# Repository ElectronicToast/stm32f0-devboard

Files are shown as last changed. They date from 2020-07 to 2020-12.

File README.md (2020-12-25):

# stm32f0-devboard
 

A minimal development board featuring an STM32F030C8T6

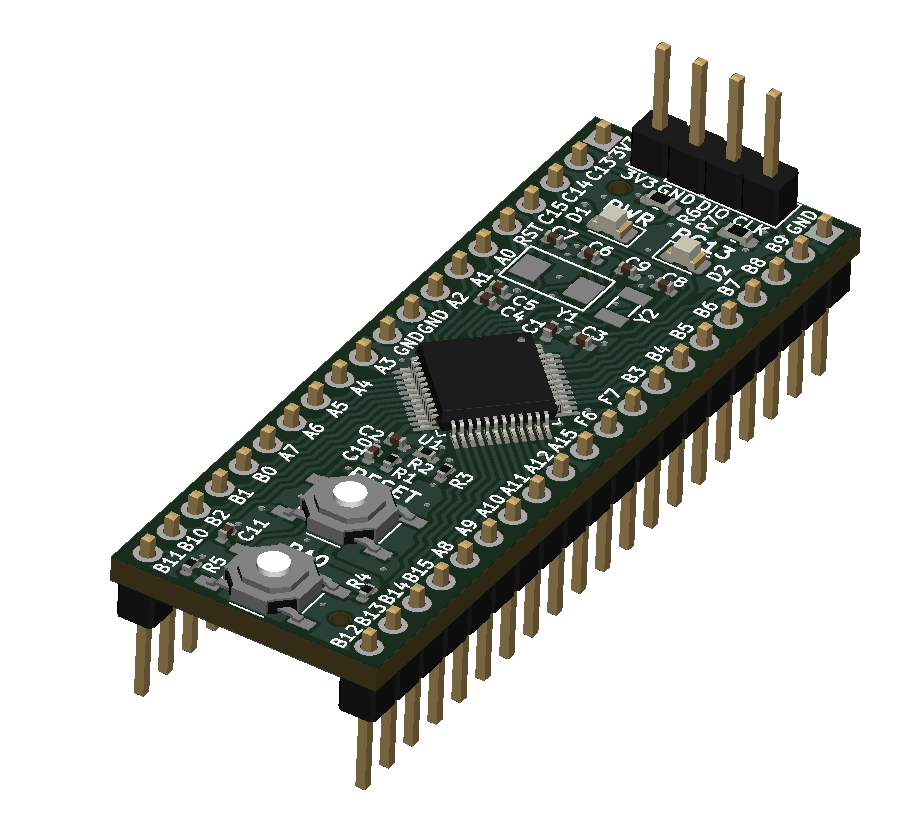
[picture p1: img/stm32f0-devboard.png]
iso


## Description
This is a minimal development board for STM32F0xxC MCUs designed for ease of turnkey assembly by JLCPCB Co. Ltd. The board includes HSE and LSE oscillators, reset and user button, power and user LED, BOOT0 boot mode select solder jumper, and a SWD programming header. All components, sans connectors, can be assembled by JLCPCB, and tooling holes for the SMT assembly process are provided.

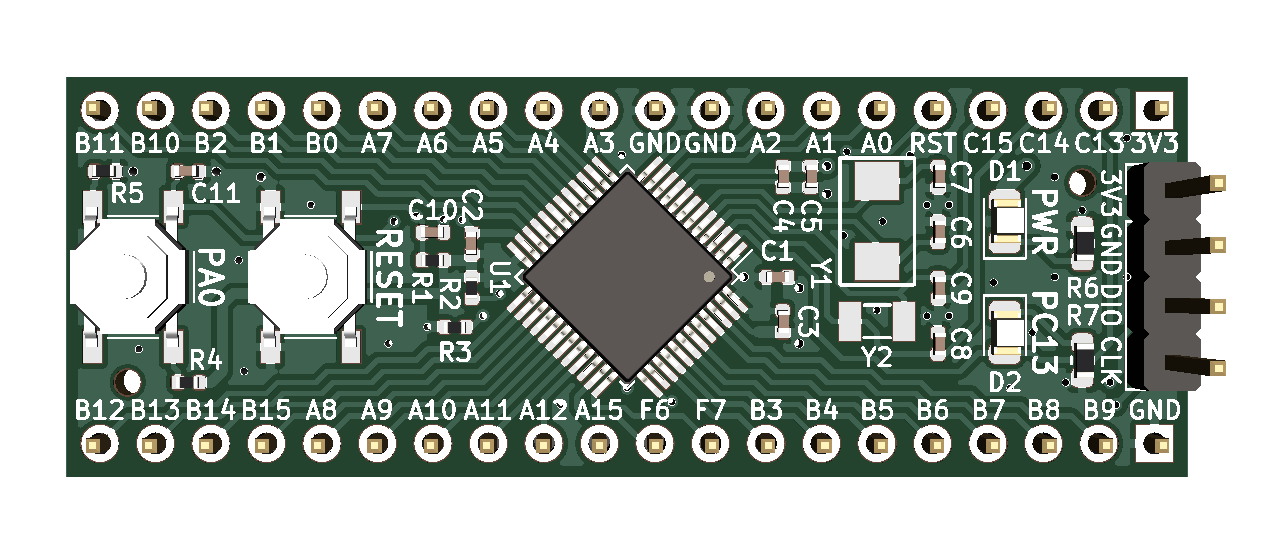
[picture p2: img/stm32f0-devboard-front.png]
front

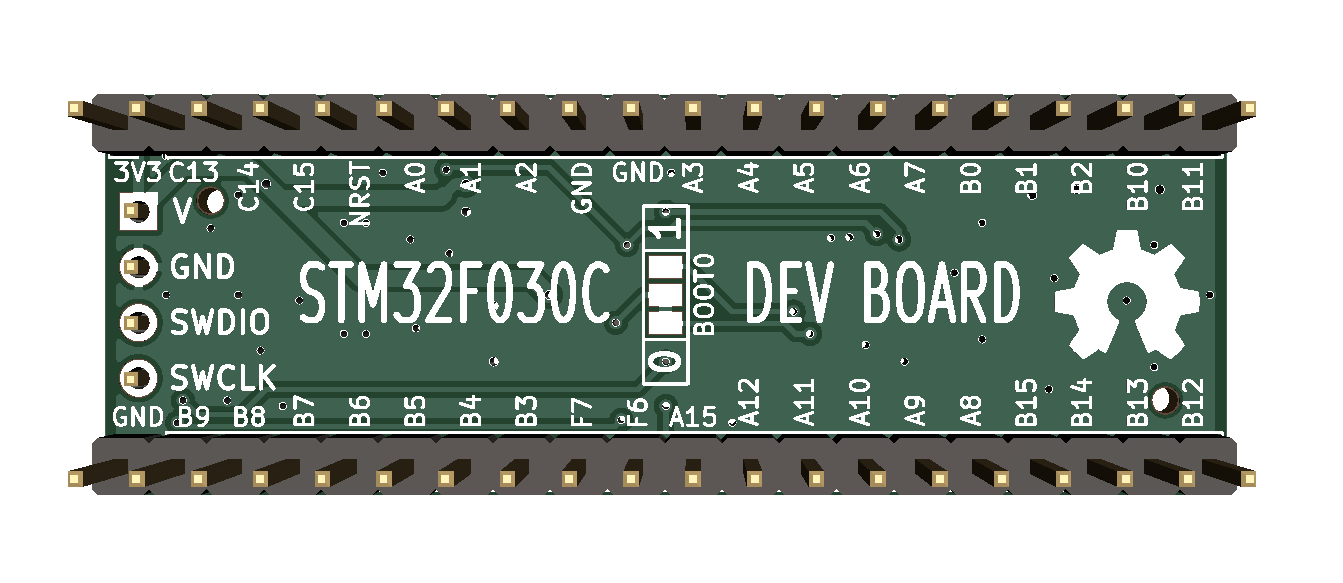
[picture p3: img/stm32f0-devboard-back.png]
back


## Licensing
This project is released under the terms of the MIT License.

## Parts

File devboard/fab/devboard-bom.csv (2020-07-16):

Comment | Designator | Footprint | LCSC Part#
4.7uF | C1 | 0402_C | C23733
100nF | C2,C3,C10,C11 | 0402_C | C1525
10nF | C4 | 0402_C | C15195
1uF | C5 | 0402_C | C52923
33pF | C6,C7 | 0402_C | C1562
18pF | C8,C9 | 0402_C | C1549
FC-2012HRK-620D Red 0603 | D1 | 0805_LED | C84256
C2293 Blue LED | D2 | 0805_LED | C2293
10K | R2,R3,R1,R4 | 0402_R | C25744
100 | R5 | 0402_R | C25076
510 | R6 | 0603_R | C23193
330 | R7 | 0603_R | C23138
TS-1187A-C-C-B | SW1,SW2 | SW-4_5.1x5.1x1.7 | C318889
STM32F030C8T6 | U1 | LQFP48 | C23922
X50328MSB2GI 8MHz | Y1 | SMD-5032_2P | C115962
Q13FC1350000400 32.768kHz | Y2 | SMD-3215_2P | C32346

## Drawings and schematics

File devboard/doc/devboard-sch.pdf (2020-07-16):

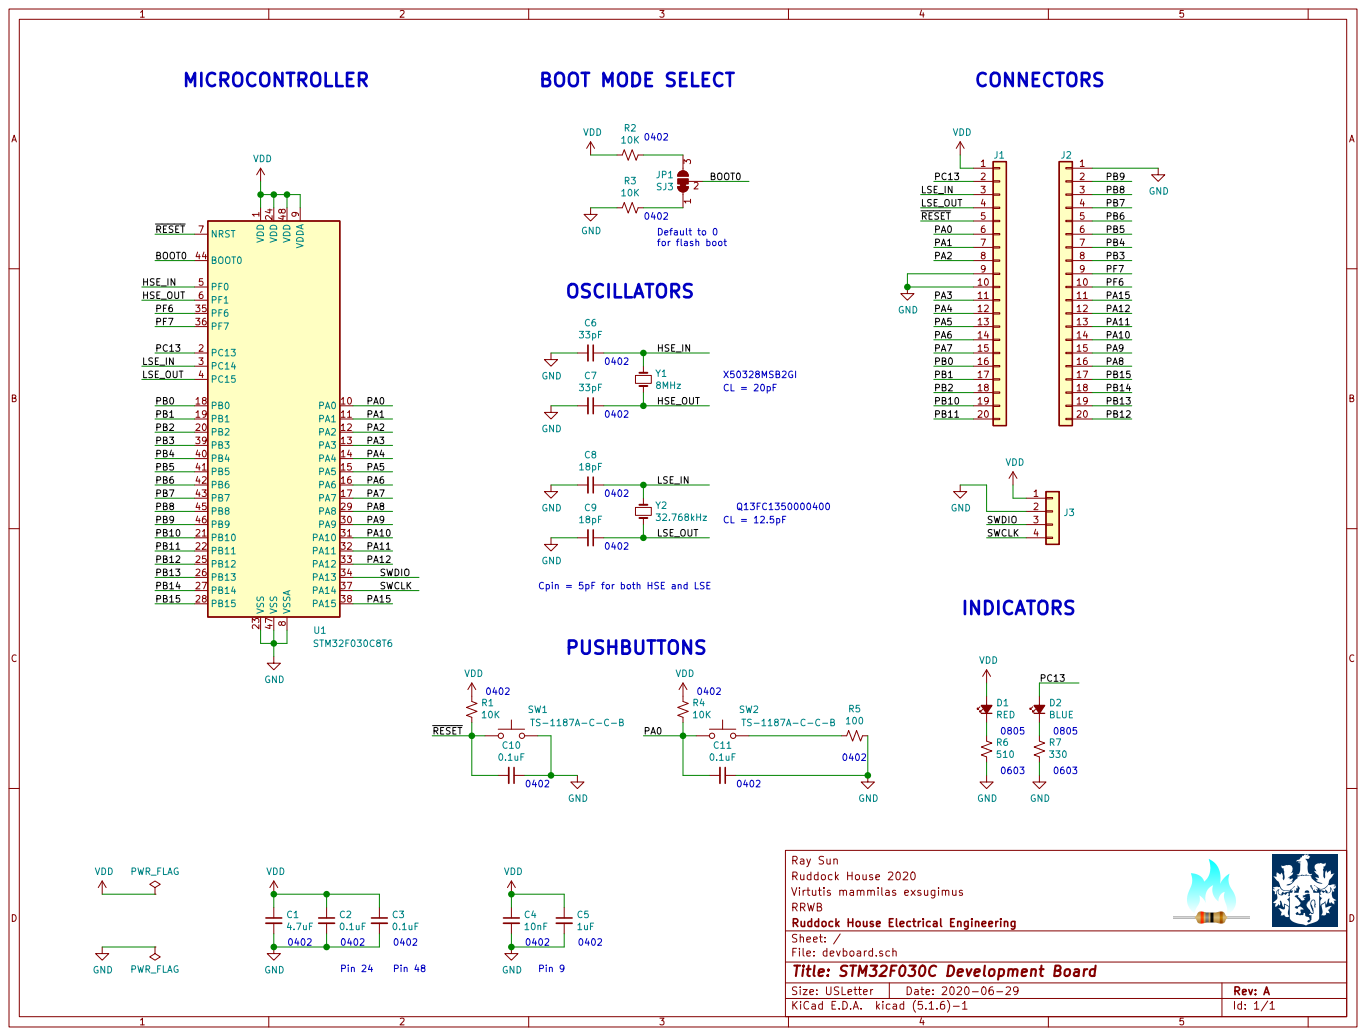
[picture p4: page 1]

1 PA0 10 PA1 11 PA2 12 PA3 13 PA4 14 PA5 15 PA6 16 PA7 17 PB0 18 PB1 19 PC13 2 PB2 20 PB10 21 PB11 22 VSS 23 VDD 24 PB12 25 PB13 26 PB14 27 PB15 28 PA8 29 PC14 3 PA9 30 PA10 31 PA11 32 PA12 33 PA13 34 PF6 35 PF7 36 PA14 37 PA15 38 PB3 39 PC15 4 PB4 40 PB5 41 PB6 42 PB7 43 BOOT0 44 PB8 45 PB9 46 VSS 47 VDD 48 PF0 5 PF1 6 NRST 7 VSSA

Cpin = 5pF for both HSE and LSE

Virtutis mammilas exsugimus Ruddock House 2020 Ray Sun

File: devboard.sch Sheet: / Ruddock House Electrical Engineering RRWB

Id: 1/1 Title: STM32F030C Development Board

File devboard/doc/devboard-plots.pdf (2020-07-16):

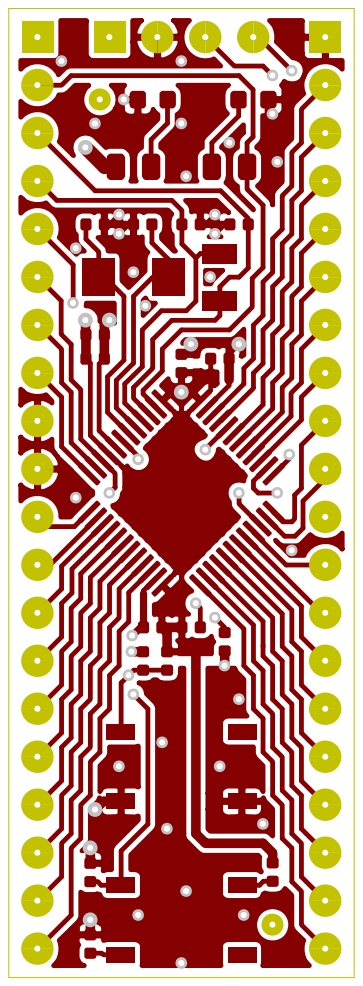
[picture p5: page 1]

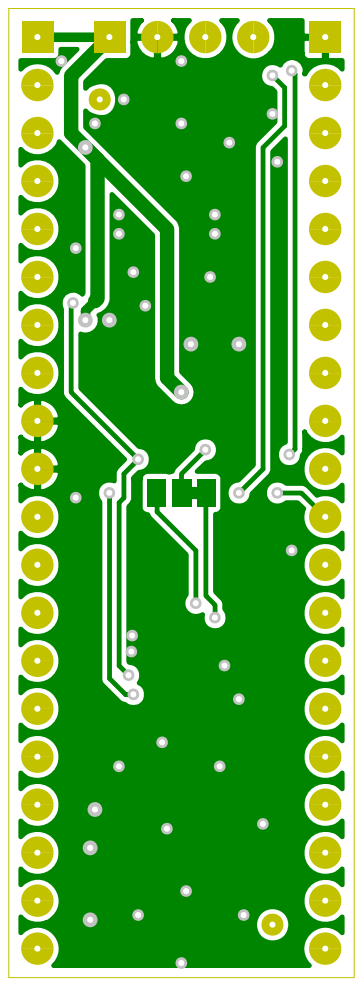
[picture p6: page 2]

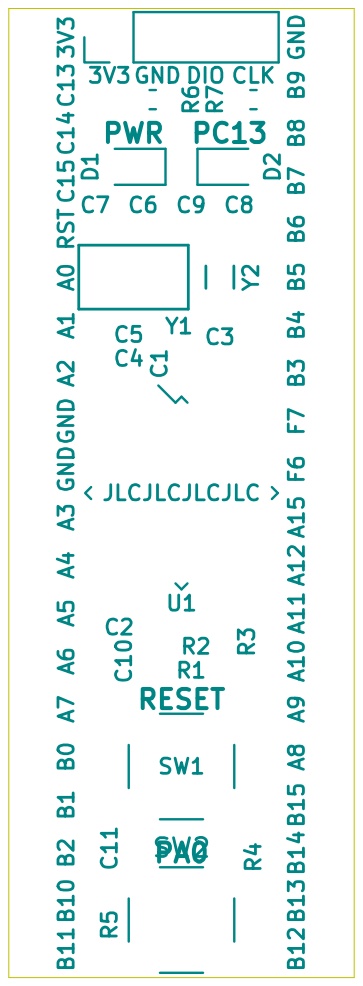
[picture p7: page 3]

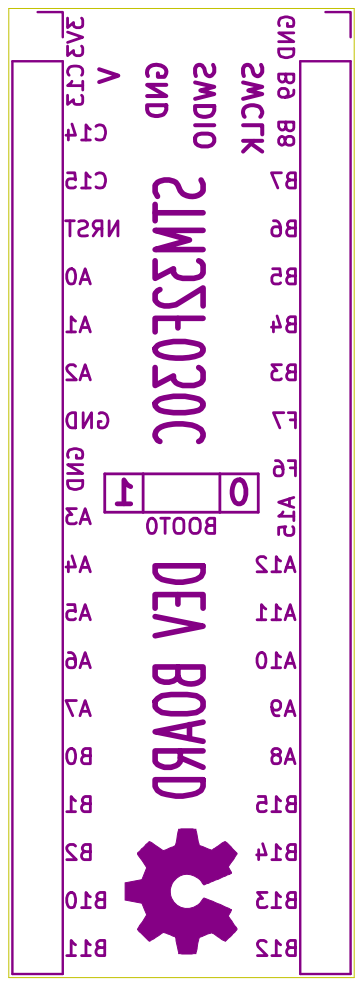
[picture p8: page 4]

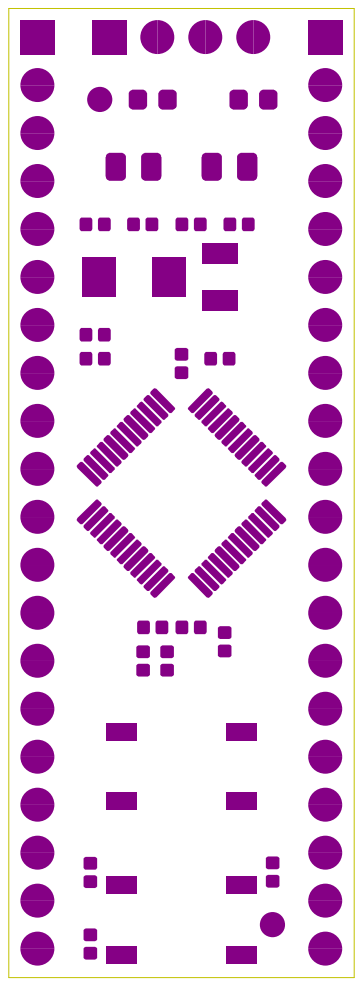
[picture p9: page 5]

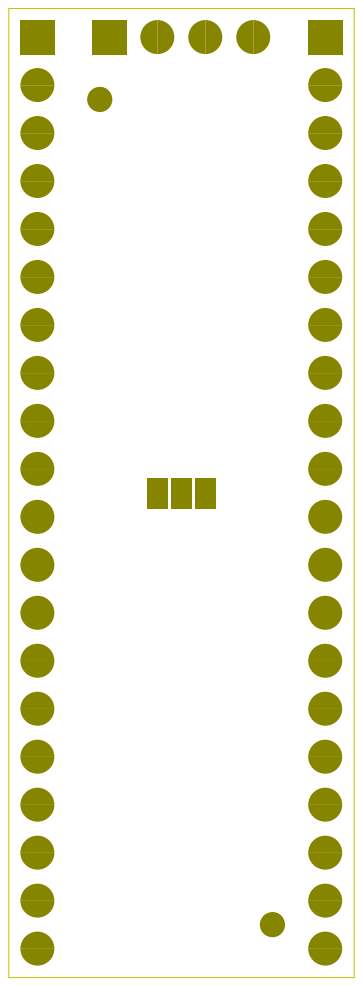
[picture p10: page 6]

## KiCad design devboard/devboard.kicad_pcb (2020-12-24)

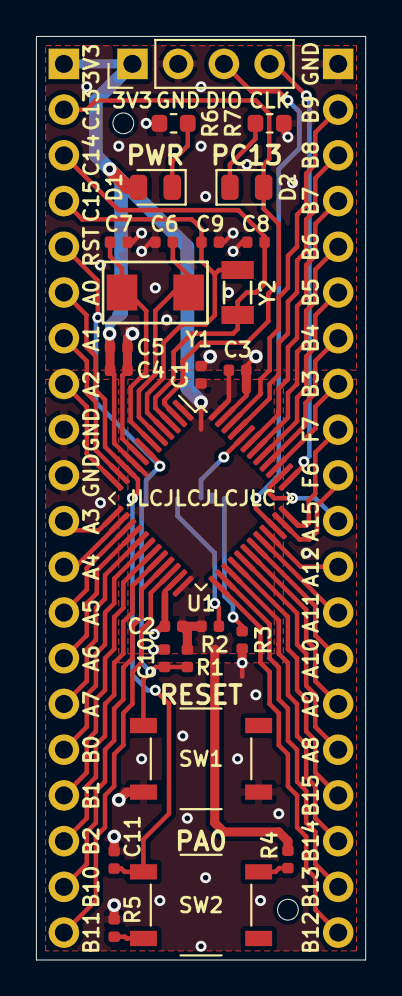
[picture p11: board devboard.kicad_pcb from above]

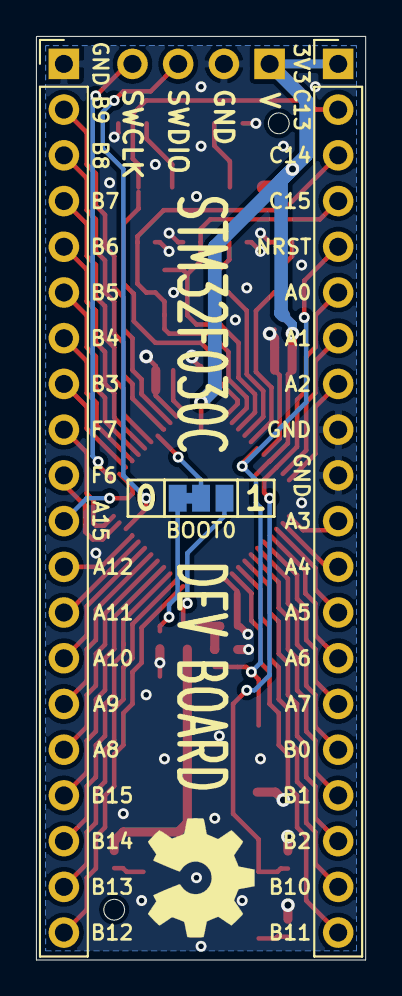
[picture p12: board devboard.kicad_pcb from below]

Board: 2 copper layers, 18.3 x 51.3 mm, 29 parts (3 on the bottom side), 48 nets.

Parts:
C1: 4.7uF; C_0402_1005Metric
C2, C3, C10, C11: 0.1uF; C_0402_1005Metric
C4: 10nF; C_0402_1005Metric
C5: 1uF; C_0402_1005Metric
C6, C7: 33pF; C_0402_1005Metric
C8, C9: 18pF; C_0402_1005Metric
D1: RED; LED_0805_2012Metric
D2: BLUE; LED_0805_2012Metric
J1, J2: PinHeader_0.1_01x20; PinHeader_1x20_P2.54mm_Vertical
J3: PinHeader_0.1_01x04; PinHeader_1x04_P2.54mm_Vertical
JP1: SJ3; SolderJumper-3_P1.3mm_Bridged12_Pad1.0x1.5mm_NoMark
R1, R2, R3, R4: 10K; R_0402_1005Metric
R5: 100; R_0402_1005Metric
R6: 510; R_0603_1608Metric
R7: 330; R_0603_1608Metric
SW1, SW2: TS-1187A-C-C-B; SW_Push_PTS526
U1: STM32F030C8T6; LQFP-48_7x7mm_P0.5mm
Y1: 8MHz; Crystal_X50328MSB2GI
Y2: 32.768kHz; Crystal_Q13FC1350000400

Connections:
/BOOT0: JP1.2, U1.44
/HSE_IN: C6.1, U1.5, Y1.1
/HSE_OUT: C7.1, U1.6, Y1.2
/LSE_IN: C8.1, J1.3, U1.3, Y2.1
/LSE_OUT: C9.1, J1.4, U1.4, Y2.2
/PA0: C11.2, J1.6, R4.1, SW2.1, U1.10
/PA1: J1.7, U1.11
/PA2: J1.8, U1.12
/PA3: J1.11, U1.13
/PA4: J1.12, U1.14
/PA5: J1.13, U1.15
/PA6: J1.14, U1.16
/PA7: J1.15, U1.17
/PA8: J2.16, U1.29
/PA9: J2.15, U1.30
/PA10: J2.14, U1.31
/PA11: J2.13, U1.32
/PA12: J2.12, U1.33
/PA15: J2.11, U1.38
/PB0: J1.16, U1.18
/PB1: J1.17, U1.19
/PB2: J1.18, U1.20
/PB3: J2.8, U1.39
/PB4: J2.7, U1.40
/PB5: J2.6, U1.41
/PB6: J2.5, U1.42
/PB7: J2.4, U1.43
/PB8: J2.3, U1.45
/PB9: J2.2, U1.46
/PB10: J1.19, U1.21
/PB11: J1.20, U1.22
/PB12: J2.20, U1.25
/PB13: J2.19, U1.26
/PB14: J2.18, U1.27
/PB15: J2.17, U1.28
/PC13: D2.2, J1.2, U1.2
/PF6: J2.10, U1.35
/PF7: J2.9, U1.36
/SWCLK: J3.4, U1.37
/SWDIO: J3.3, U1.34
/~RESET: C10.2, J1.5, R1.1, SW1.1, U1.7
GND: C1.2, C2.2, C3.2, C4.2, C5.2, C6.2, C7.2, C8.2, C9.2, C10.1, C11.1, J1.9, J1.10, J2.1, J3.2, R3.2, R5.1, R6.1, R7.1, SW1.2, U1.8, U1.23, U1.47
unnamed: D1.1, R6.2
unnamed: D2.1, R7.2
unnamed: JP1.1, R3.1
unnamed: JP1.3, R2.1
unnamed: R5.2, SW2.2
VDD: C1.1, C2.1, C3.1, C4.1, C5.1, D1.2, J1.1, J3.1, R1.2, R2.2, R4.2, U1.1, U1.9, U1.24, U1.48

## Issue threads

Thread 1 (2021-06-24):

PC13 incorrectly used to drive LED

guberti, 2021-06-24:
From page 30 on [the datasheet for the STM32F030](https://datasheet.lcsc.com/lcsc/1811061717_STMicroelectronics-STM32F030C8T6_C23922.pdf):
<pre>
1. PC13, PC14 and PC15 are supplied through the power switch. Since the switch only sinks a limited amount
of current (3 mA), the use of GPIOs PC13 to PC15 in output mode is limited:
- The speed should not exceed 2 MHz with a maximum load of 30 pF.
<b>- These GPIOs must not be used as current sources (e.g. to drive an LED).</b>
</pre>
However, on this devboard the LED D2 is connected to PC13 with a 330 ohm resistor:

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

 It would be best practice to connect the LED to a different pin of the STM32F030.
